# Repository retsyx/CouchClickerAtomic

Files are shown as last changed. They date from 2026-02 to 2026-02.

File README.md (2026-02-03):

# Couch Clicker Atomic

The keyboard for your couch.

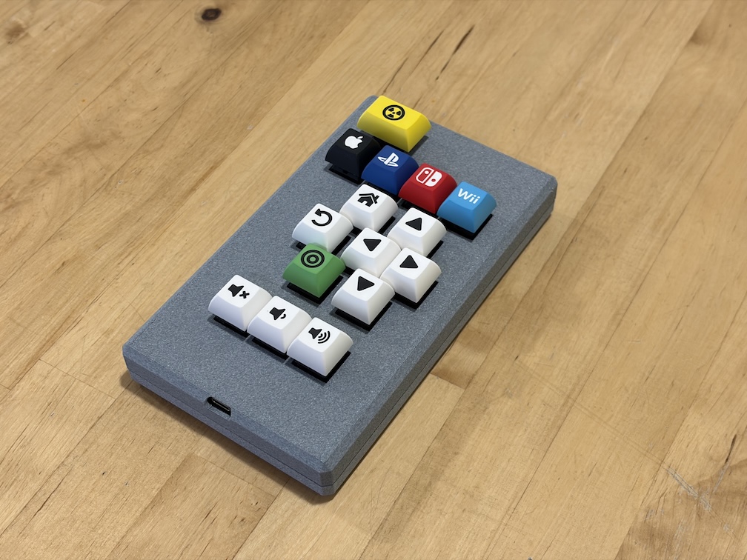
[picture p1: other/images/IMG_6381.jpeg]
Couch Clicker Atomic


Couch Clicker Atomic is a Bluetooth, mechanical key, home theater remote control designed for use with [Amity](https://github.com/retsyx/amity) - home theater control over HDMI-CEC that works! (really)

Watch the video

Watch the video (https://www.youtube.com/embed/6jkzTikYONI)

## Using Couch Clicker Atomic

Couch Clicker Atomic works with Amity like any other compatible remote. To read more about Amity and its operation, visit the [Amity page](https://github.com/retsyx/amity).

To clear Couch Clicker Atomic's Bluetooth pairing and to re-pair, press and hold the `Power` and `Volume Up` buttons for 6 seconds.

To reset Couch Clicker Atomic, press and hold the `Power` and `Mute` buttons for 6 seconds.

## It's a Keyboard

Couch Clicker Atomic is really just a standard wireless Bluetooth keyboard. It may work (with some customization) with other home theater devices that have bluetooth remote controls that are really keyboard devices, like Google TVs or Amazon Fire TVs.

## Hardware

### PCB

The remote is based on a Seeed Studio XIAO nRF52840 board. The PCB design and manufacturing files are [here](other/hardware).

### Keycaps

A sample design file to get your own keycaps from [Yuzu Keycaps](https://yuzukeycaps.com) is available [here](other/keycaps/yuzu.json).

### 3D Printed Case

STEP files for a 3D printed case are available [here](other/case).

### LiPo Battery

A LiPo with a JST 2 connector that fits in the case should work. The battery should be at most 10mm thick, and 30mm wide. Ensure the battery leads in the connector are the same polarity as the connector on Couch Clicker Atomic. If they are not, battery connector pins can be easily pried out with a utility knife to reverse their position in the connector.

[This LiPo battery](https://www.amazon.com/dp/B0CNLNZFQL) works well.

## Firmware

### ZMK

Download the ZMK firmware image from [here](https://github.com/retsyx/CouchClickerAtomic/releases/latest/download/cca-seeeduino_xiao_ble-zmk.uf2). Install it using the standard ZMK installation method - [documented here](https://zmk.dev/docs/user-setup#install-the-firmware).

When the remote is fully assembled in the case, to update the firmware, the remote must be reset to the bootloader. Press and hold the `Power`, `Select` and `Back` buttons for 10 seconds to reset to the bootloader.

Couch Clicker Atomic ZMK code is licensed under the [MIT license](MIT-LICENSE.md).

### KMK

Alternatively, you may prefer to use a CircuitPython based firmware with KMK. Code and instructions for installing KMK are [here](other/kmk).

Couch Clicker Atomic KMK code is licensed under the [GPLv3 license](GPLv3-LICENSE.md).

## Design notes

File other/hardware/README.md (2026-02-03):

# Couch Clicker Atomic PCB

<p style="text-align: center;">
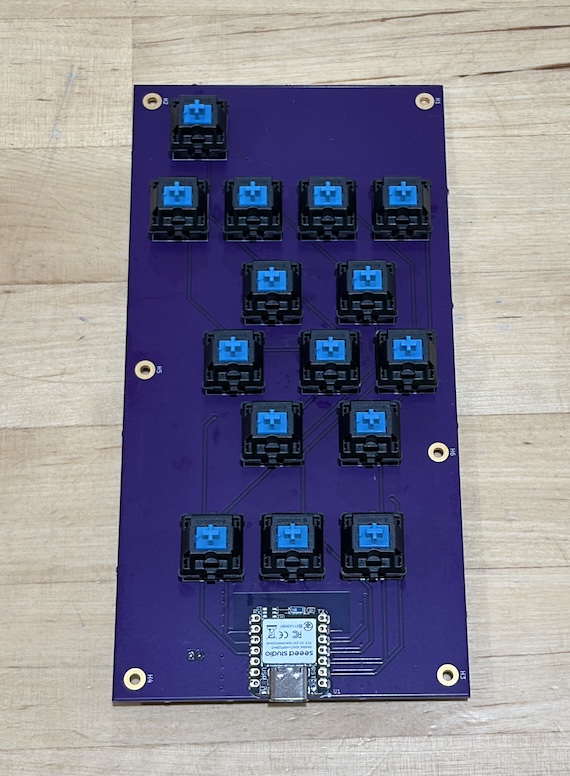
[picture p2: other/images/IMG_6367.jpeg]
PCB

</p>

Gerber files and an example BOM file are in the [mfr folder](board/mfr/).

## BOM

* 1x [Seeed Studio XIAO BLE nRF52840](https://www.seeedstudio.com/Seeed-XIAO-BLE-nRF52840-p-5201.html)
* 15x [Cherry MX key switches, or similar, PCB mount](https://www.digikey.com/en/products/detail/cherry-americas-llc/MX1A-E1NW/20180)
* 15x [1N4148W diodes](https://www.digikey.com/en/products/detail/anbon-semiconductor-int-l-limited/1N4148W/17284377)
* 1x [JST 2.0 Connector](https://www.digikey.com/en/products/detail/jst-sales-america-inc/S2B-PH-K-S/926626)

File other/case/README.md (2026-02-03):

# Couch Clicker Atomic 3D Printable Case

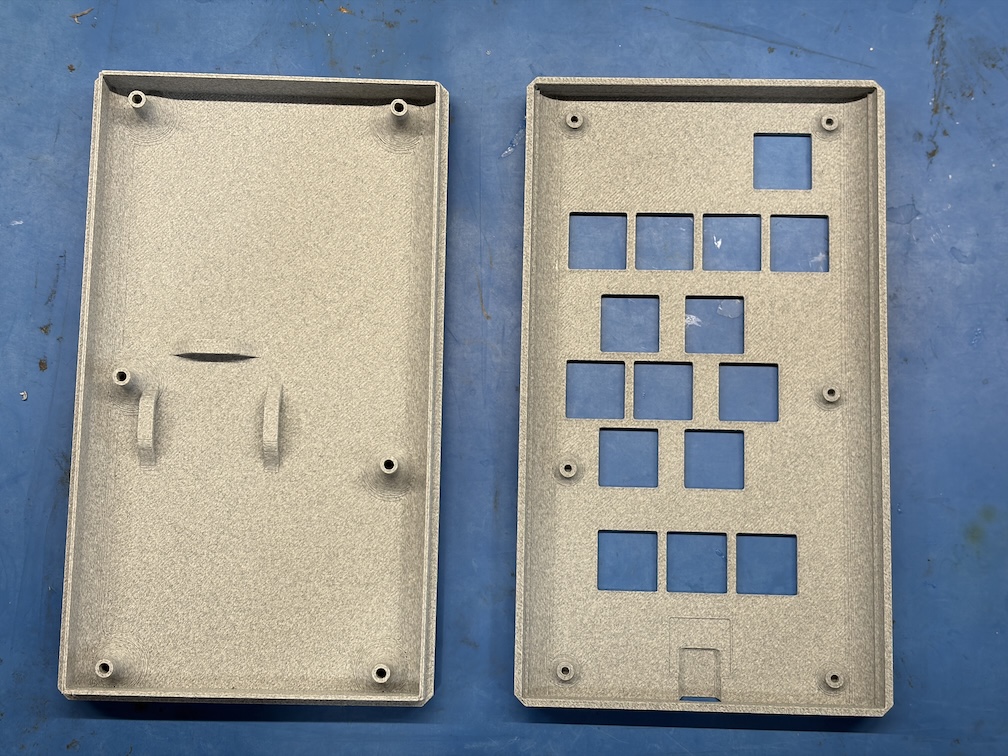
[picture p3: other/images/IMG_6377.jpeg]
Case Halves


* [Case Top](case-top.step)
* [Case Bottom](case-bottom.step)

## Printing

Print without supports. Use 6x 18mm M2.5 hex socket head machine screws.

## Assembly

1. In the bottom case part, remove the sacrifical layer in the screw holes by placing a screw in the hole from the inside and gently tapping it with a mallet to break the layer. Pull out the screw and remove any remaining plastic bits from the other side. Ream the screw head holes with the hex key for the screws to ensure no plastic remains.
2. In the bottom case part, insert a length of hook and loop cable wrap tape through the battery bridges to hold the battery.
3. Slide the USB-C port through the top case cover hole, and push the PCB switches through the top case cover holes.
4. Attach the battery to the PCB.
5. Fasten the battery to the bottom case with the hook and loop tape.
6. Press the case parts together, and fasten the screws.

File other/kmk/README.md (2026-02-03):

# KMK Firmware for Couch Clicker Atomic

## Installing KMK Firmware

* [Install CircuitPython](https://learn.adafruit.com/welcome-to-circuitpython/installing-circuitpython) on the XIAO board.

* Copy the entire contents of [this folder](.) into the CircuitPython drive mounted from the XIAO board.

* Optionally, rename the CircuitPython volume to 'CLICKER'

## Licensing

* KMK Keyboard firmware is licensed under the [GPLv3 license](https://github.com/KMKfw/kmk_firmware?tab=License-1-ov-file#readme).
* Adafruit BLE code is licensed under the [MIT license](https://github.com/adafruit/Adafruit_CircuitPython_BLE?tab=MIT-1-ov-file#readme).
* Couch Clicker Atomic KMK python code is licensed under the [GPLv3 license](../../GPLv3-LICENSE.md).

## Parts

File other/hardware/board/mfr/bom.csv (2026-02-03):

Item # | Designator | Qty | Manufacturer | Mfg Part # | Descrption / Value | Package / Footprint | Type
1 | SW1,SW2,SW3,SW4,SW5,SW6,SW7,SW8,SW9,SW10,SW11,SW12,SW13,SW14,SW15 | 15 | Cherry Americas LLC | CH197-ND | SWITCH PUSH SPST-NO 0.01A 12V | Through Hole | Through Hole
2 | D1,D2,D3,D4,D5,D6,D7,D8,D9,D10,D11,D12,D13,D14,D15 | 15 | ANBON SEMICONDUCTOR (INT'L) LIMITED | 1N4148W | DIODE STANDARD 75V 150MA SOD123 | SOD123 | SMD
3 | U1 | 1 | Seeed Studio | 102010448 | XIAO nRF52840 | SMD | SMD
4 | J1 | 1 | JST | S2B-PH-K-S | CONN HEADER R/A 2POS 2MM | Through Hole | Through Hole

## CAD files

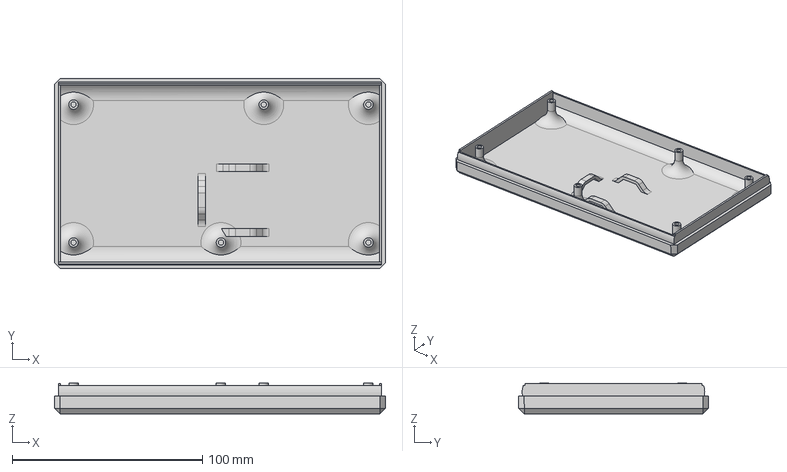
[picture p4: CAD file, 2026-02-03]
other/case/case-bottom.step
174.0 x 100.0 x 16.3 mm

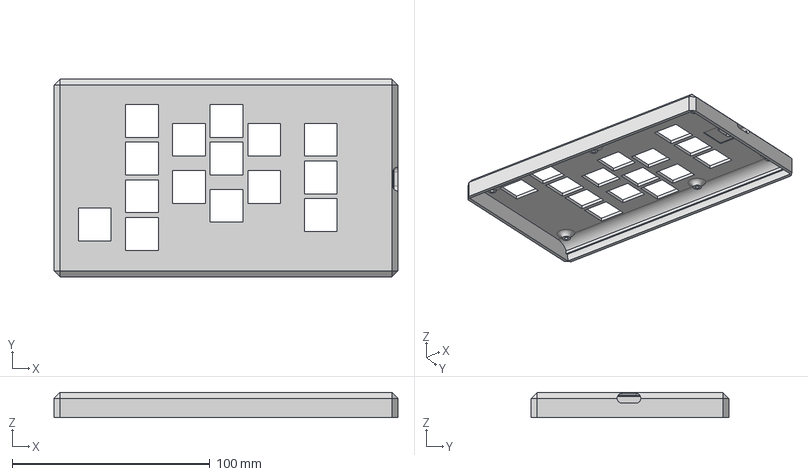
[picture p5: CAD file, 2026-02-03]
other/case/case-top.step
174.0 x 100.0 x 12.6 mm

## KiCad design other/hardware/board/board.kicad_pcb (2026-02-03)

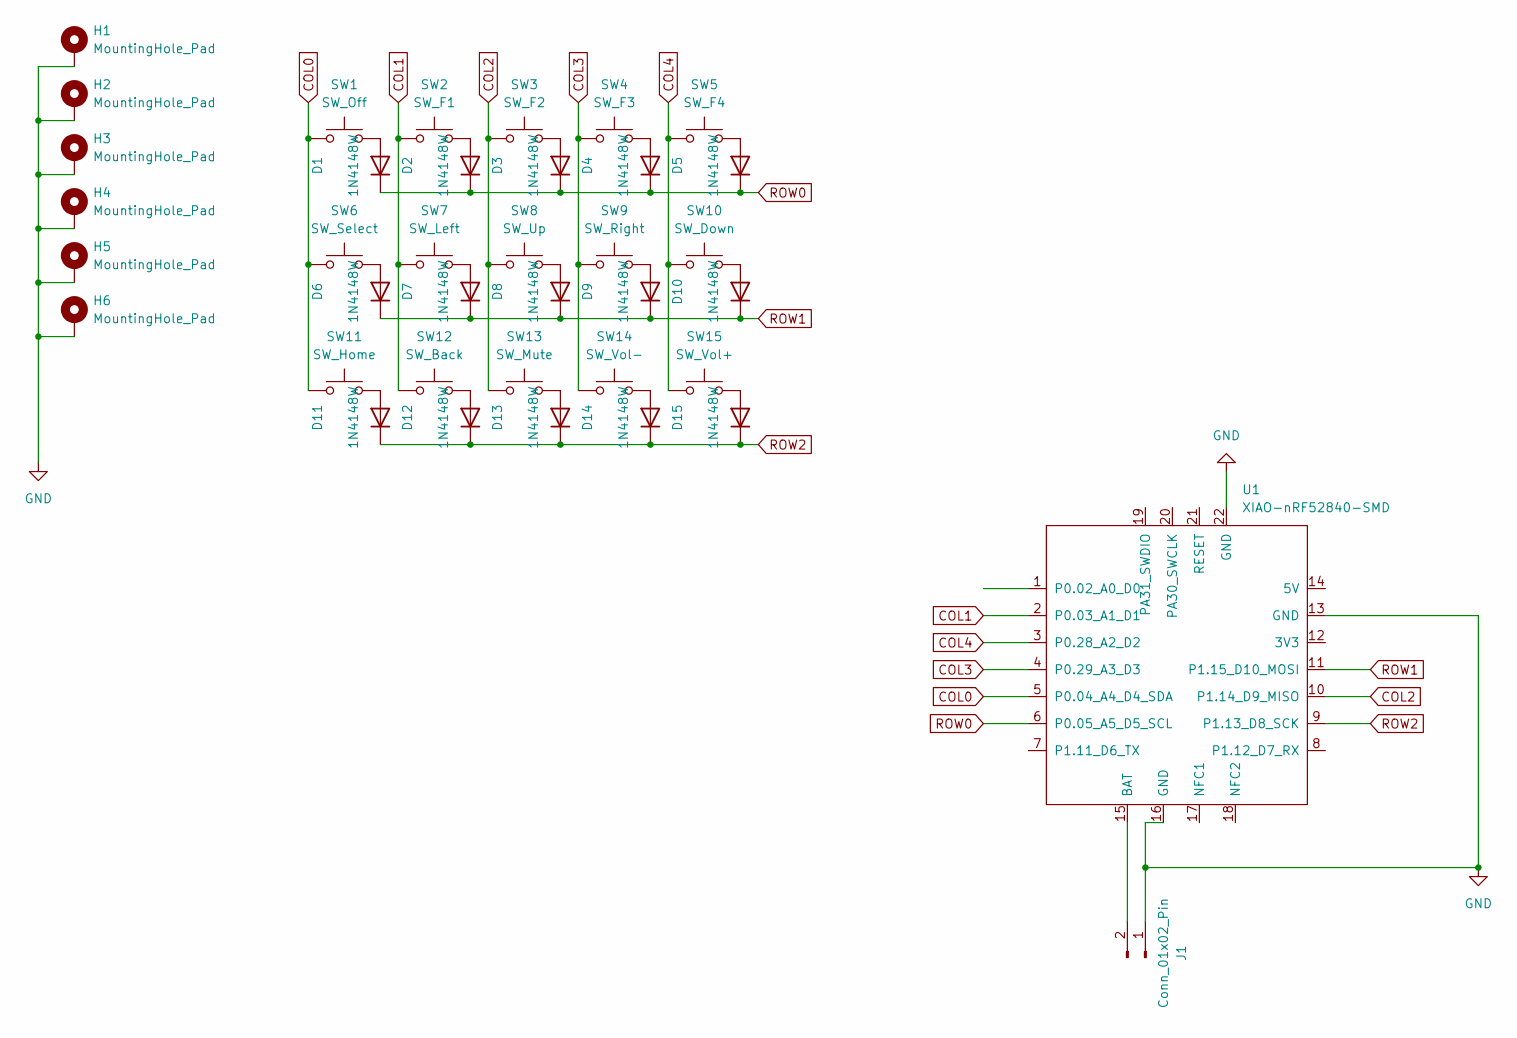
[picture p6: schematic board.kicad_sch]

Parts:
D1, D2, D3, D4, D5, D6, D7, D8, D9, D10, D11, D12, D13, D14, D15: 1N4148W; D_SOD-123
H1, H2, H3, H4, H5, H6: MountingHole_Pad; MountingHole_2.5mm_Pad
J1: Conn_01x02_Pin; JST_PH_S2B-PH-K_1x02_P2.00mm_Horizontal
SW1: SW_Off; SW_Cherry_MX_1.50u_PCB
SW2: SW_F1; SW_Cherry_MX_1.00u_PCB
SW3: SW_F2; SW_Cherry_MX_1.00u_PCB
SW4: SW_F3; SW_Cherry_MX_1.00u_PCB
SW5: SW_F4; SW_Cherry_MX_1.00u_PCB
SW6: SW_Select; SW_Cherry_MX_1.00u_PCB
SW7: SW_Left; SW_Cherry_MX_1.00u_PCB
SW8: SW_Up; SW_Cherry_MX_1.00u_PCB
SW9: SW_Right; SW_Cherry_MX_1.00u_PCB
SW10: SW_Down; SW_Cherry_MX_1.00u_PCB
SW11: SW_Home; SW_Cherry_MX_1.00u_PCB
SW12: SW_Back; SW_Cherry_MX_1.00u_PCB
SW13: SW_Mute; SW_Cherry_MX_1.00u_PCB
SW14: SW_Vol-; SW_Cherry_MX_1.00u_PCB
SW15: SW_Vol+; SW_Cherry_MX_1.00u_PCB
U1: XIAO-nRF52840-SMD

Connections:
COL0: SW1.1, SW6.1, SW11.1, U1.5 (P0.04_A4_D4_SDA)
COL1: SW2.1, SW7.1, SW12.1, U1.2 (P0.03_A1_D1)
COL2: SW3.1, SW8.1, SW13.1, U1.10 (P1.14_D9_MISO)
COL3: SW4.1, SW9.1, SW14.1, U1.4 (P0.29_A3_D3)
COL4: SW5.1, SW10.1, SW15.1, U1.3 (P0.28_A2_D2)
GND: H1.1, H2.1, H3.1, H4.1, H5.1, H6.1, J1.1, U1.13 (GND), U1.16 (GND), U1.22 (GND)
unnamed: D1.2 (A), SW1.2
unnamed: D2.2 (A), SW2.2
unnamed: D3.2 (A), SW3.2
unnamed: D4.2 (A), SW4.2
unnamed: D5.2 (A), SW5.2
unnamed: D6.2 (A), SW6.2
unnamed: D7.2 (A), SW7.2
unnamed: D8.2 (A), SW8.2
unnamed: D9.2 (A), SW9.2
unnamed: D10.2 (A), SW10.2
unnamed: D11.2 (A), SW11.2
unnamed: D12.2 (A), SW12.2
unnamed: D13.2 (A), SW13.2
unnamed: D14.2 (A), SW14.2
unnamed: D15.2 (A), SW15.2
unnamed: J1.2, U1.15 (BAT)
ROW0: D1.1 (K), D2.1 (K), D3.1 (K), D4.1 (K), D5.1 (K), U1.6 (P0.05_A5_D5_SCL)
ROW1: D6.1 (K), D7.1 (K), D8.1 (K), D9.1 (K), D10.1 (K), U1.11 (P1.15_D10_MOSI)
ROW2: D11.1 (K), D12.1 (K), D13.1 (K), D14.1 (K), D15.1 (K), U1.9 (P1.13_D8_SCK)

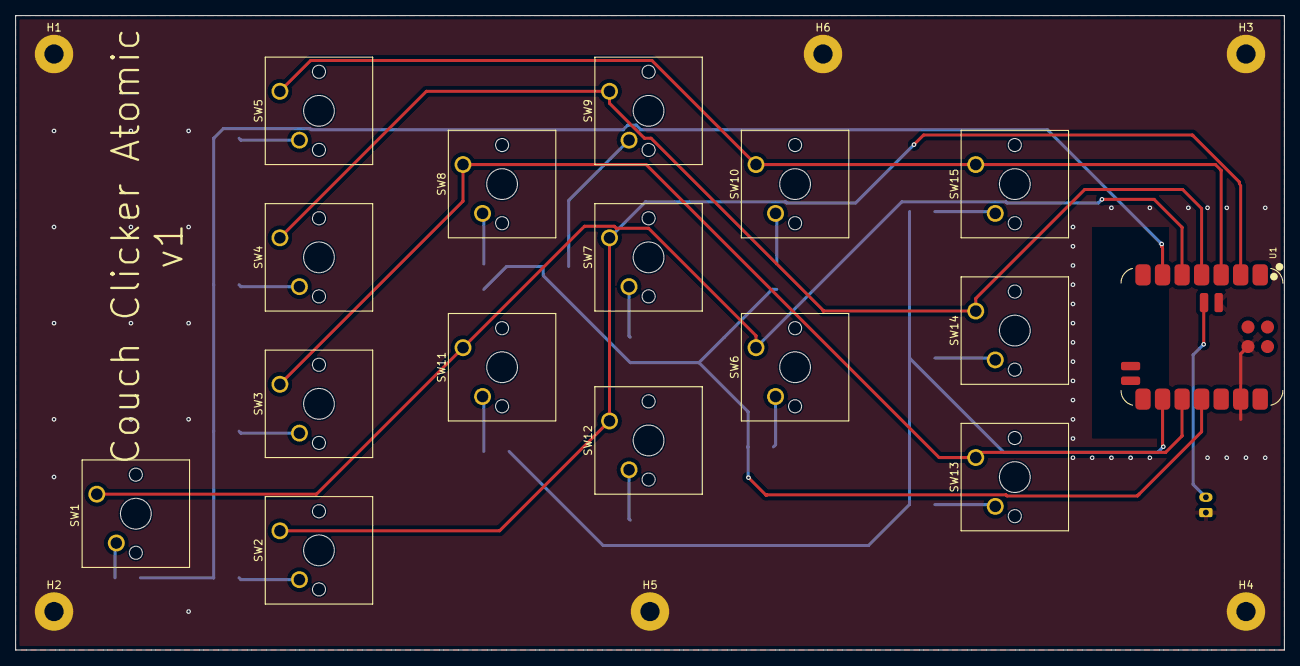
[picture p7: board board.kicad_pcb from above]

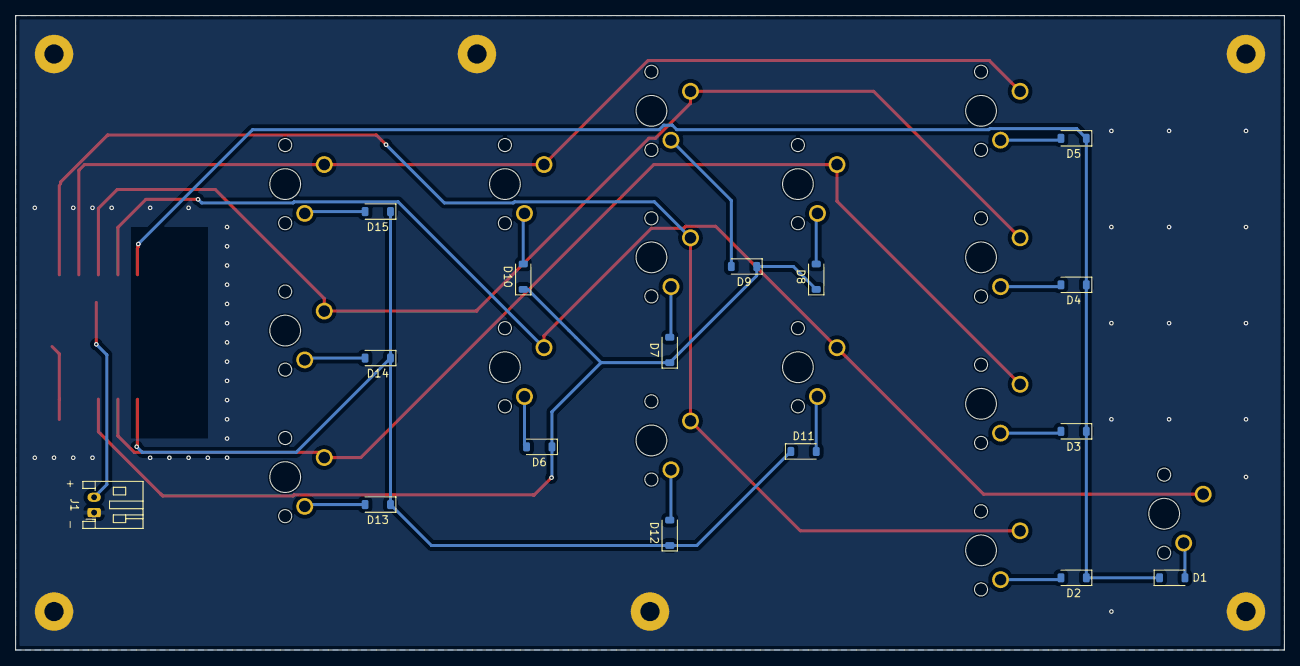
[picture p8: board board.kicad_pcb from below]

Board: 2 copper layers, 165.0 x 82.5 mm, 38 parts (16 on the bottom side), 25 nets.

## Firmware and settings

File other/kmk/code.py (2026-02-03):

print("Starting")

import board

from kmk.kmk_keyboard import KMKKeyboard
from kmk.keys import KC, ConsumerKey, KeyboardKey, make_key
from kmk.scanners import DiodeOrientation
from kmk.hid import HIDModes
from kmk.modules.combos import Combos, Chord
from kmk.modules.power import Power
from kmk.extensions.media_keys import MediaKeys


keyboard = KMKKeyboard()
combos = Combos()
keyboard.modules.append(combos)
power = Power()
keyboard.modules.append(power)

keyboard.extensions.append(MediaKeys())

codes = (
    (0x66, ('POWER',)),
    (0x4A, ('HOME',)),
)

for code, names in codes:
    make_key(names=names, constructor=KeyboardKey, code=code)

combos.combos = [
    Chord((KC.POWER, KC.MUTE, KC.VOLU), KC.BLE_DISCONNECT)
]

keyboard.col_pins = (board.D4, board.D1, board.D9, board.D3, board.D2)
keyboard.row_pins = (board.D5, board.D10, board.D8)
keyboard.diode_orientation = DiodeOrientation.COL2ROW

keyboard.keymap = [
    [KC.POWER, KC.F1, KC.F2, KC.F3, KC.F4,
     KC.ENTER, KC.LEFT, KC.UP, KC.RIGHT, KC.DOWN,
     KC.HOME, KC.ESC, KC.MUTE, KC.VOLD, KC.VOLU
    ]
]

if __name__ == '__main__':
    keyboard.go(hid_type=HIDModes.BLE, ble_name='Couch Clicker Atomic')

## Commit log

2026-01-26 BT unpair and reset on long hold of combos
    Press and hold power + mute for 6 seconds to reset/restart the firmware
    Press and hold power + volume up for 6 seconds to unbind/unpair bluetooth
2026-01-26 Increase BLE TX power
2026-01-29 Add reset to bootloader key combo
    10 second hold of power, back/esc, and select resets to the bootloader.
2026-02-03 Add HW design, KMK firmware, and documentation
    [board-B_Cu.gbr, board-B_Mask.gbr, board-B_Paste.gbr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]
